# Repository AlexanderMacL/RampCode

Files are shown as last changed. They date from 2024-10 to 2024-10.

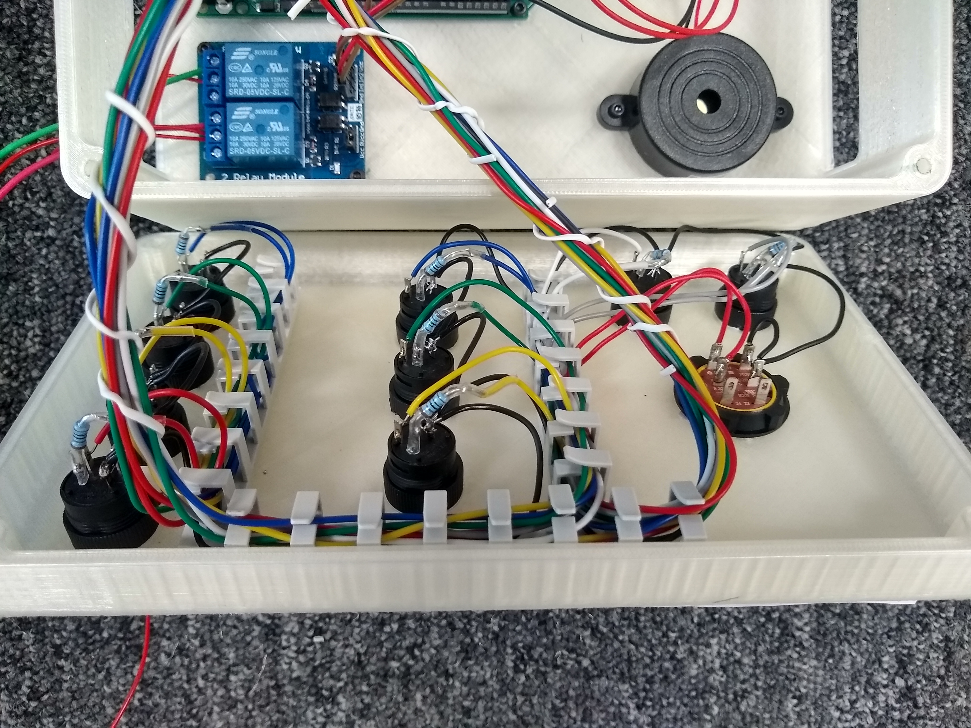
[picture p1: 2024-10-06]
Photos/IMG_20230616_105059777_HDR.jpg

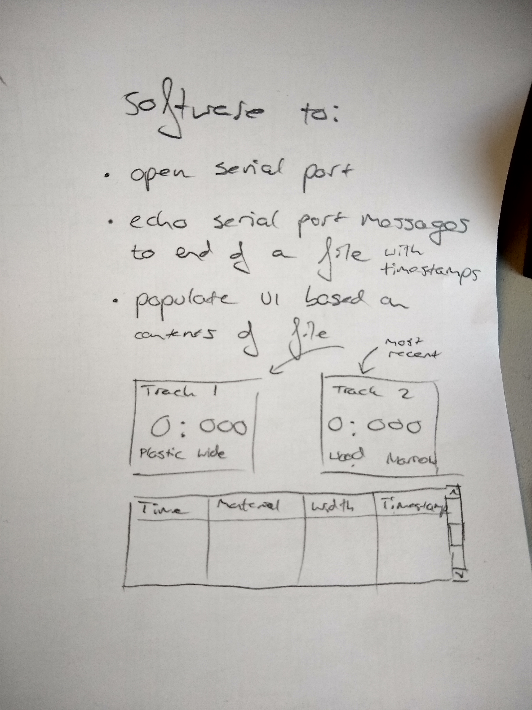
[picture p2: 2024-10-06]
Photos/IMG_20230616_143941583_HDR.jpg

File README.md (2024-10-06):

### Project Overview

- **`ControlPanel`**:  
  An Arduino app designed to run on an Arduino Mega (chosen for its ample IO capabilities to accommodate all the buttons).

- **`Leaderboard`**:  
  A WinForms Windows app designed to run on a Windows PC. It reads data sent by the Arduino through a serial port.

- **`MechDesign`**:  
  Contains various design files, including CAD files for the 3D-printed parts.

- **`Data`**:  
  Holds data obtained at the Great Exhibition Road Festival in 2023.

- **`Photos`**:  
  A collection of photos of the device.

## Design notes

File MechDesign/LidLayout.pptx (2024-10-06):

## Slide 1

Plastic

GO!

Twist to release

Narrow

Wood

Wide

Felt

Combo

1

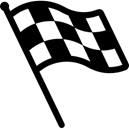
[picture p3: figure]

Track

2

Rubber

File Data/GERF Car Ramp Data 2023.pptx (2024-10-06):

## Total Runs by Material

When only one track was in use, the other, whatever its configuration, ‘did not finish’, so some of these may not have represented actual runs

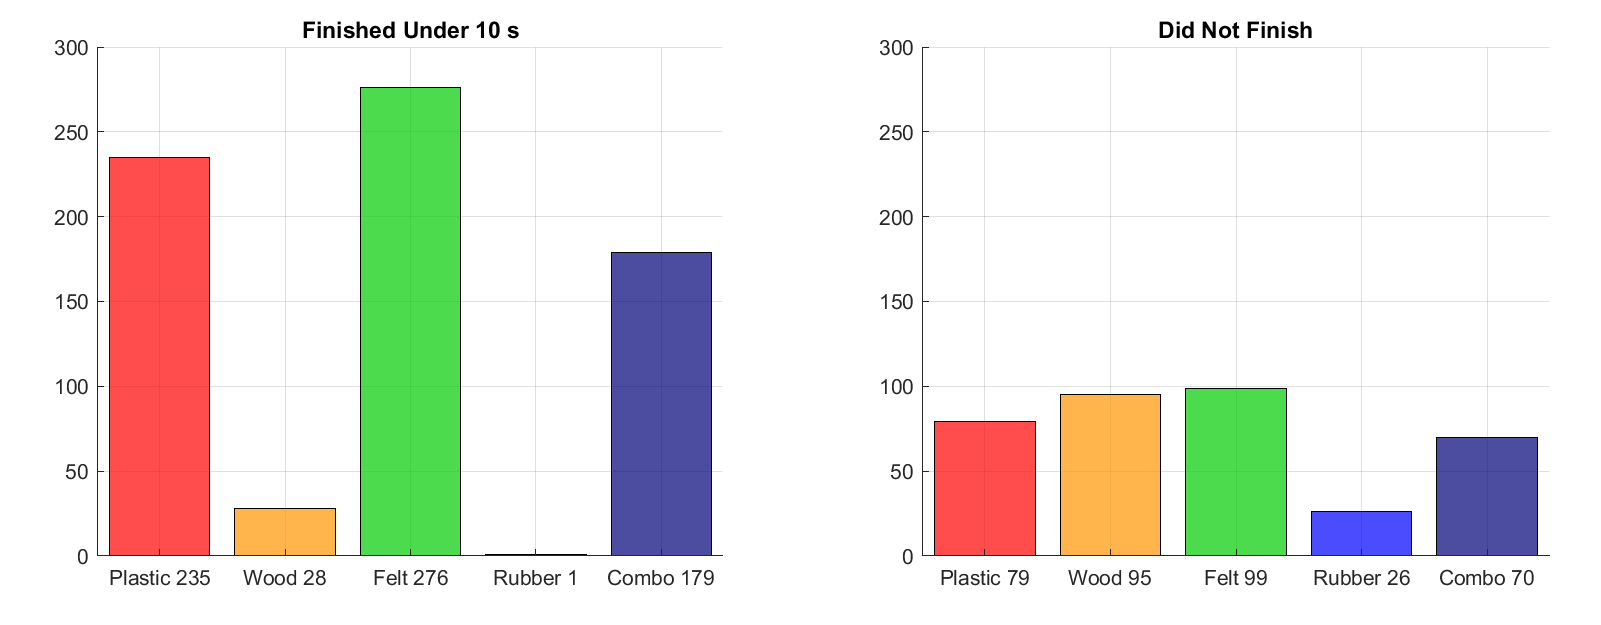
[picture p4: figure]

Over ¾ of wood did not finish the course. Rubber reliably did not finish.

## Frequency of Finish Time by Material

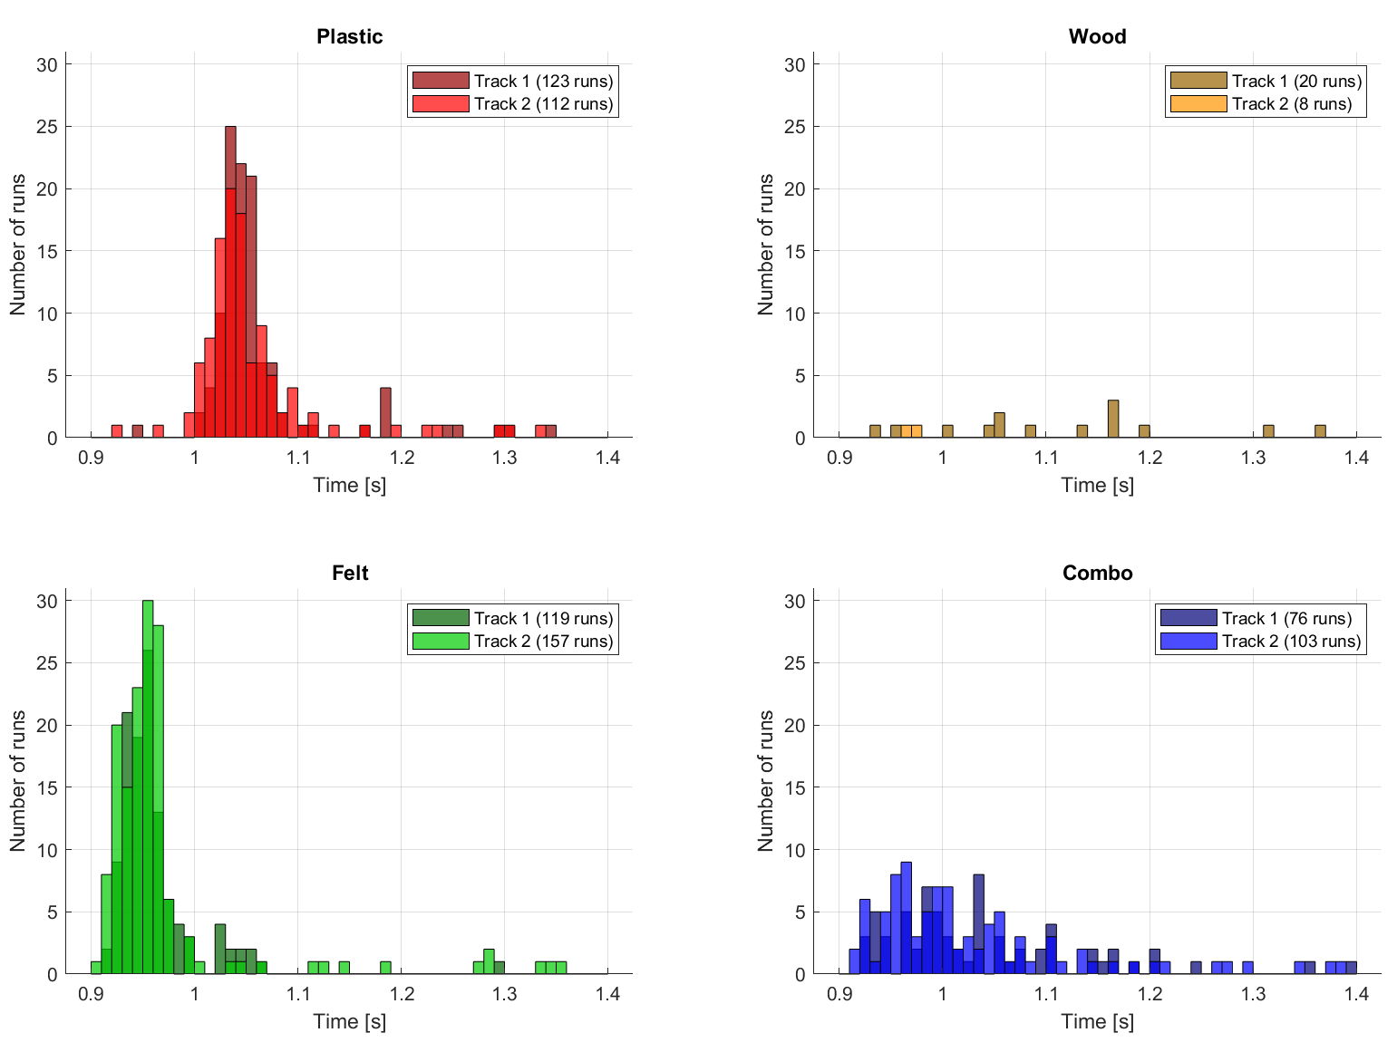
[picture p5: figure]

Felt is faster than plastic by ~0.08 s on average
(each bar represents 0.01 s)

Felt and plastic have similar standard deviations in finish time

Both tracks show the same trends and have the same mode finish time (bin size 10 ms)

## Frequency of Finish Time by Width

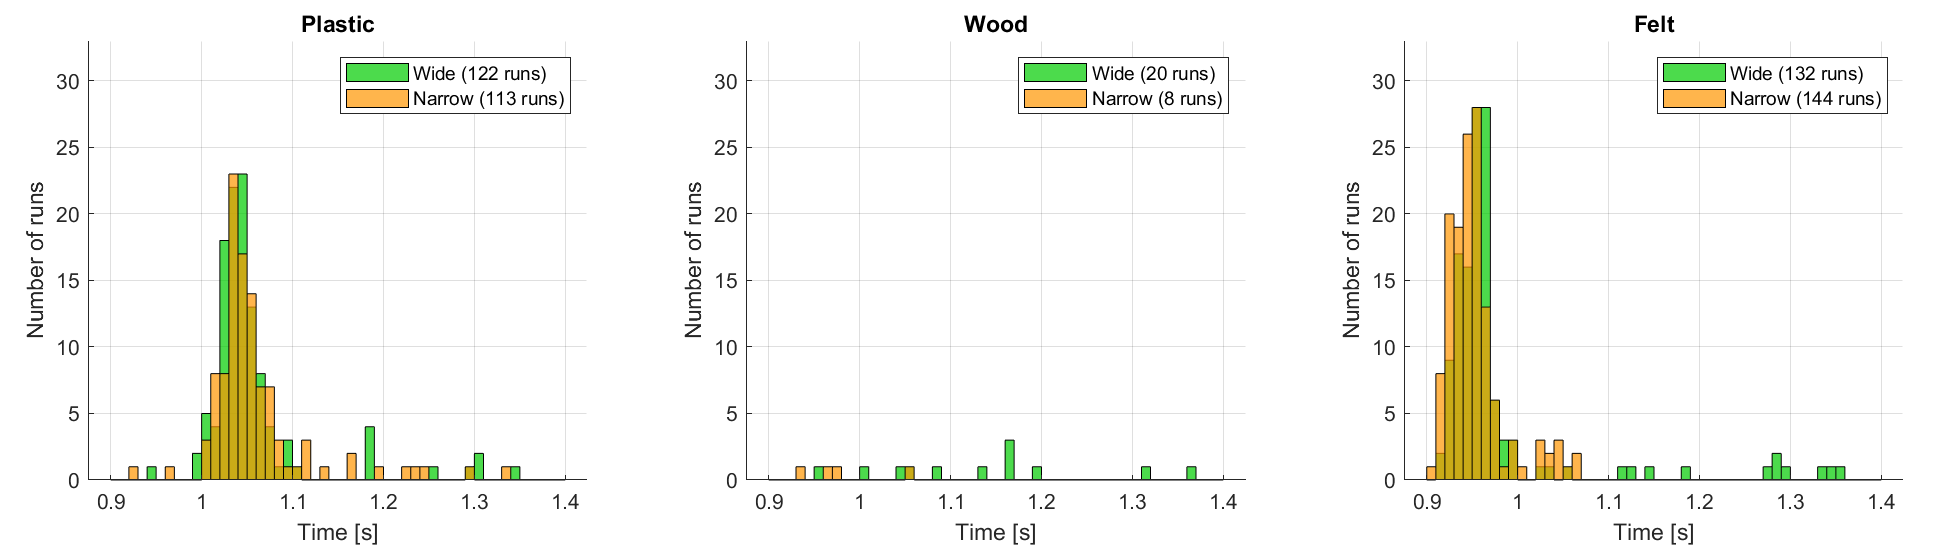
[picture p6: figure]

Mean finish time for narrow slightly faster than for wide for all materials

Results for wood are not statistically significant

Felt shows the most significant separation by width

## Activity Distribution by Time of Day

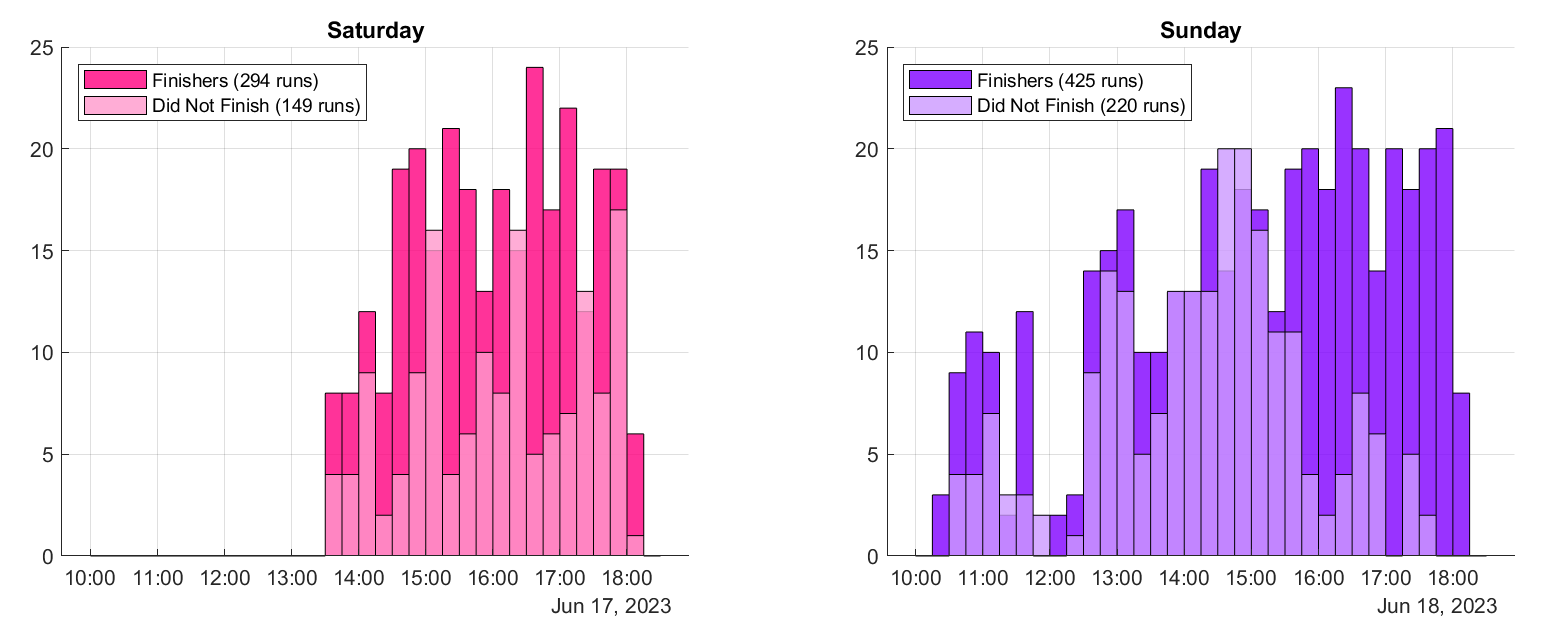
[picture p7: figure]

Regrettably, data from before lunchtime on Saturday was not recorded

The event officially opened 1100-1800

## Runs finishing in under 10 s

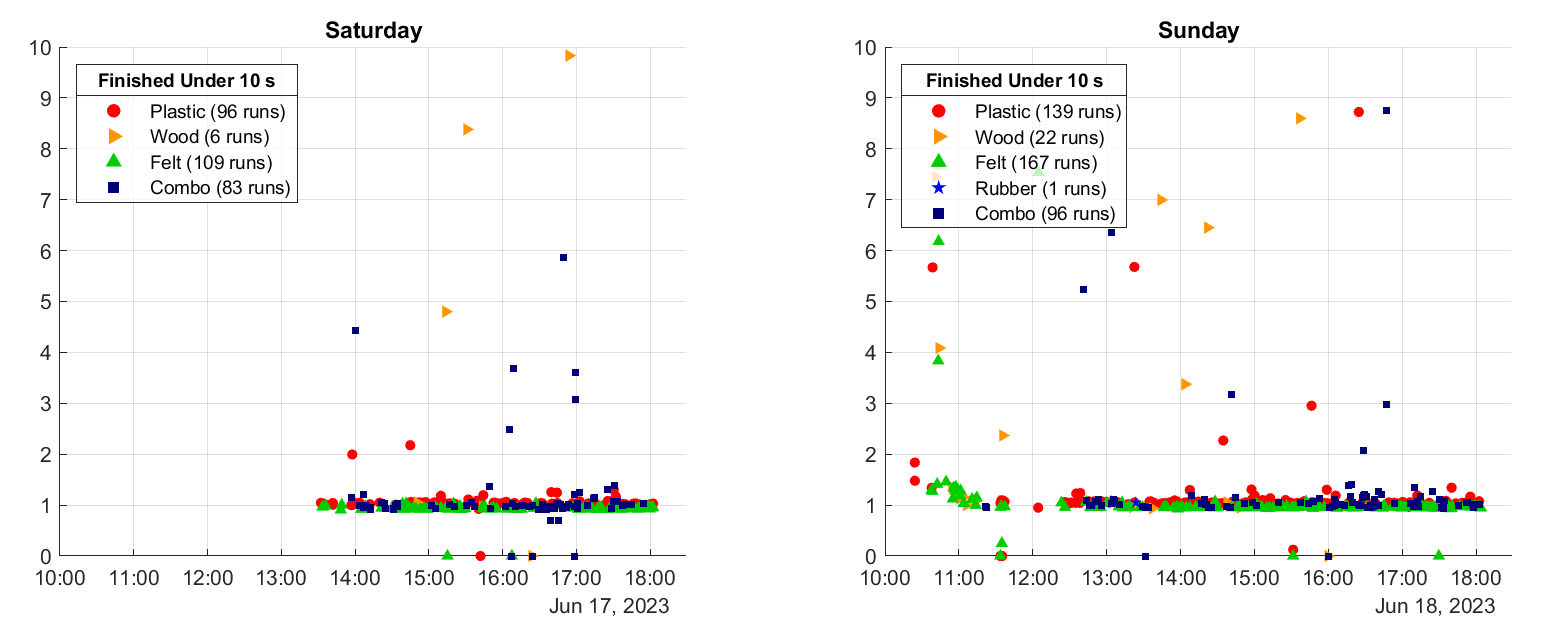
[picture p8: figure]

Runs taking more than 2 seconds occurred when cars did not finish but were not left for the full 10s, or due to other anomalies

## Runs finishing in under 2 s

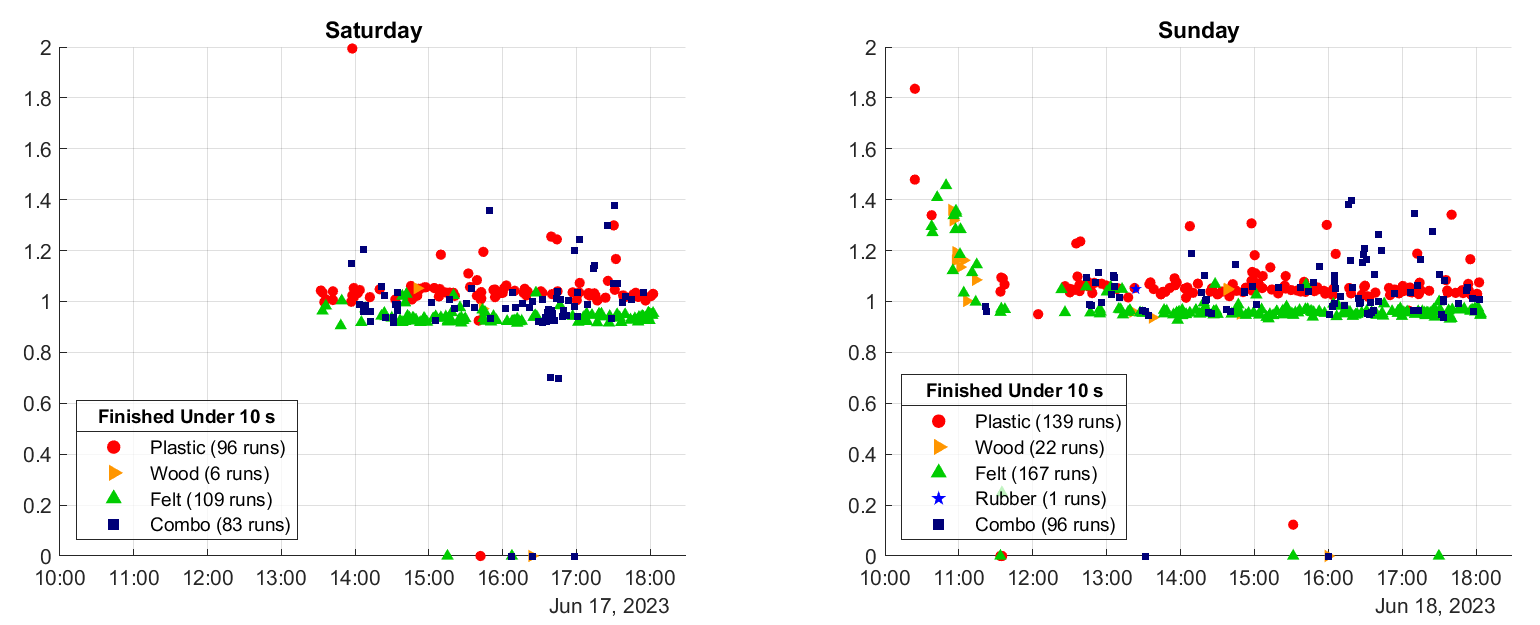
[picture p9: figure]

On Sunday the track had been cleaned overnight and for the first hour, finish times were appreciably longer until it became greasy again!

## Runs finishing in under 2 s by Track

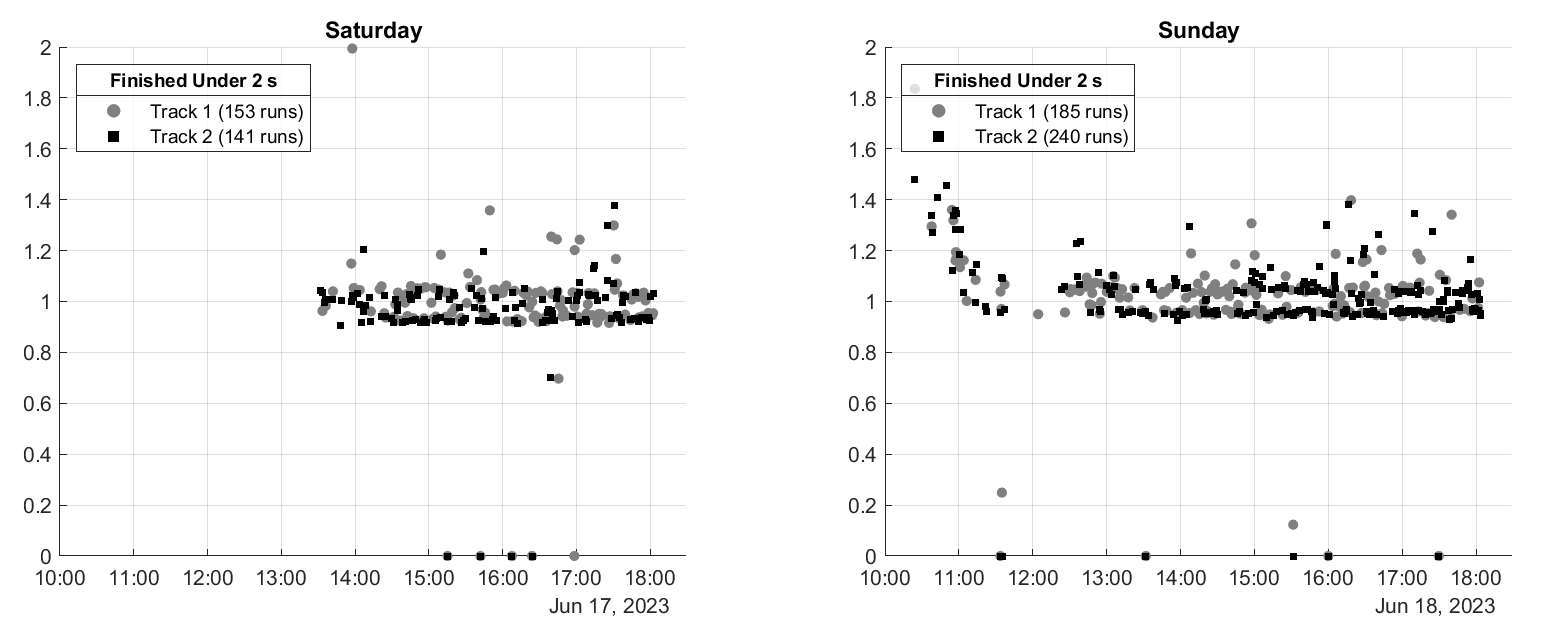
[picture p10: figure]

## Distribution of Finishers by Material

Visibility of leaderboard (showing felt to be most successful) and perhaps also intuition, created a consistent bias towards the faster materials

At approx. 1630 on both days, there was a spike in popularity of combos

This may coincide with the time that people’s uncles started joining in and trying to be clever

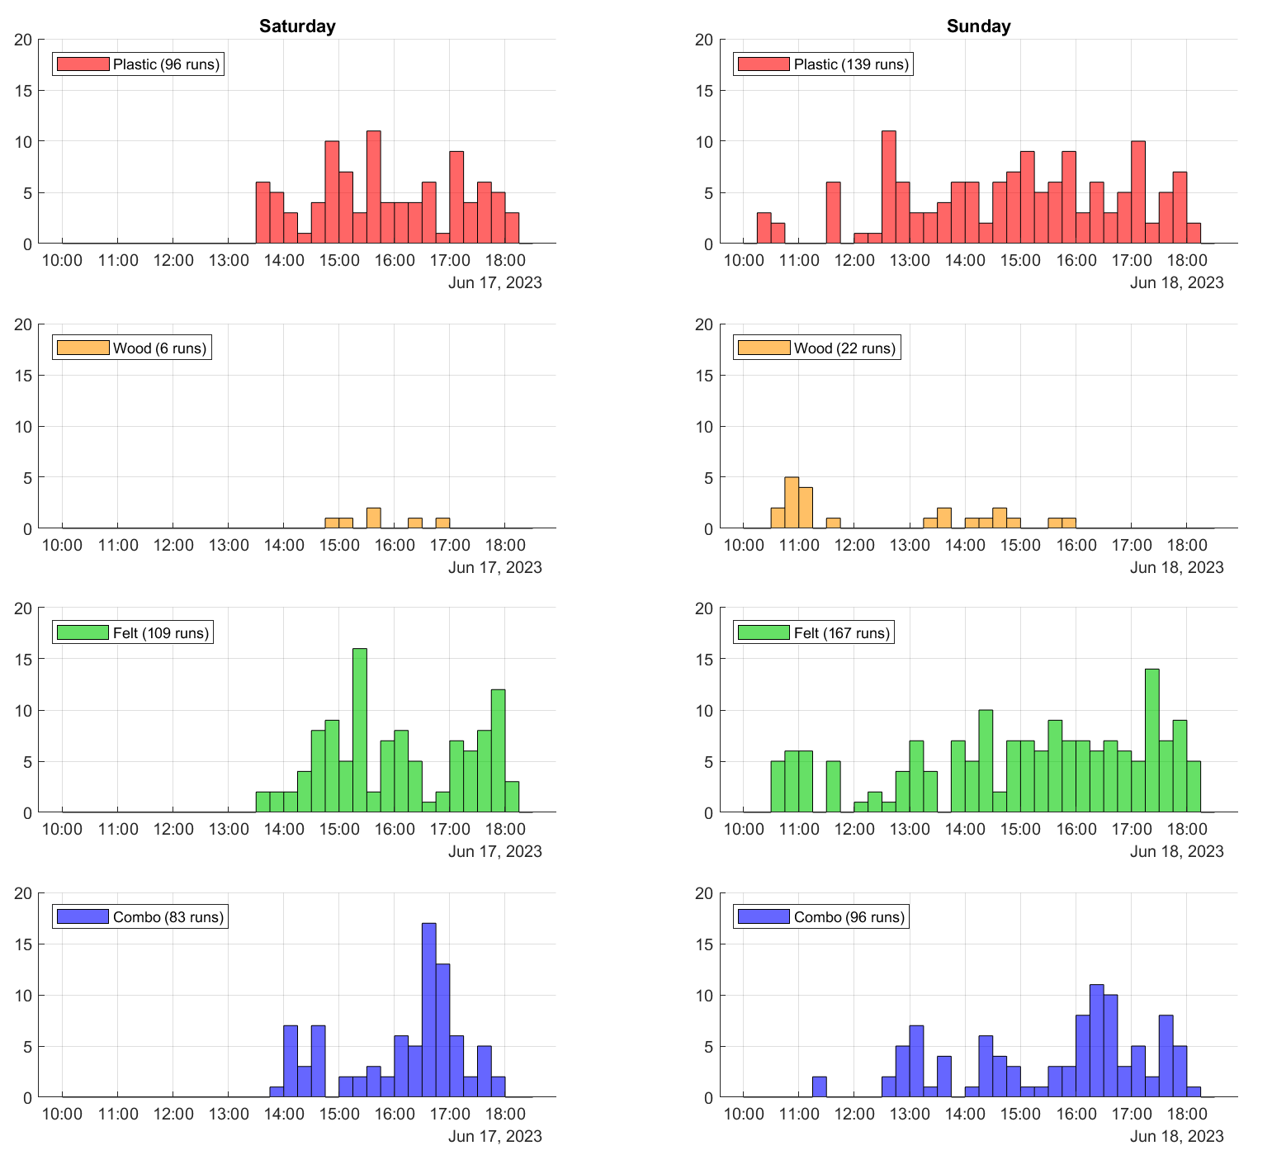
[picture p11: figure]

## Distribution of Did Not Finish by Material

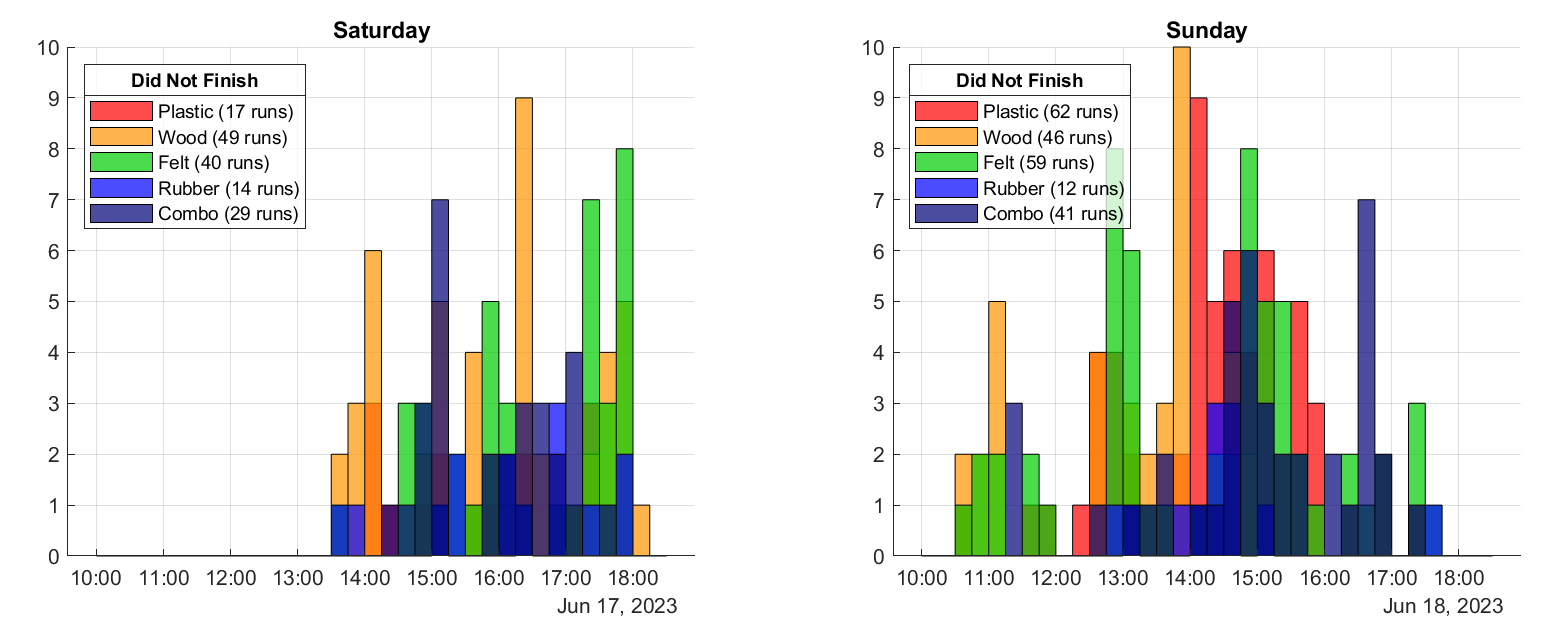
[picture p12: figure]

All 5 materials were, at different times, most frequent to not finish, for a variety of reasons including cars hitting the sides, solenoids failing to release, being assigned to a track not in use

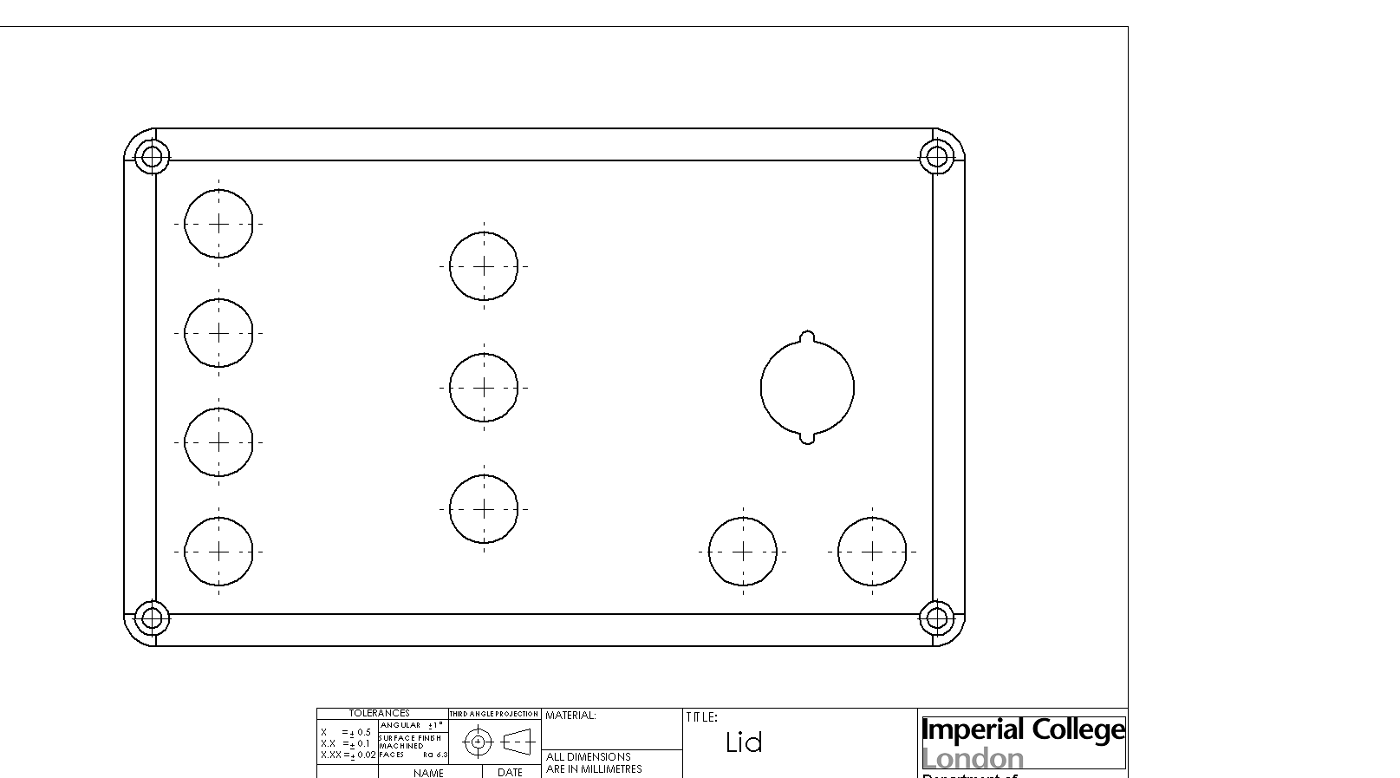
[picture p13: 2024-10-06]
MechDesign/Lid.PNG

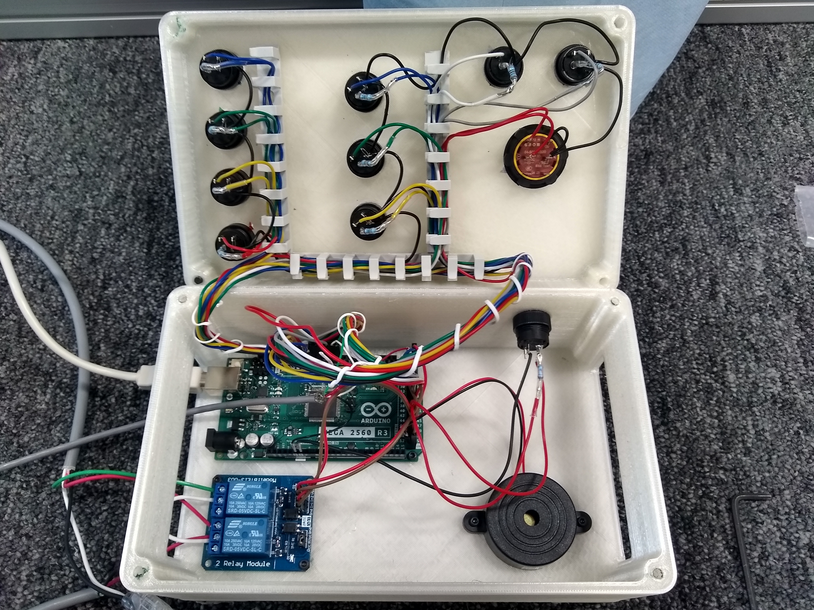
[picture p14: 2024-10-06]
Photos/IMG_20230616_121205236_HDR.jpg

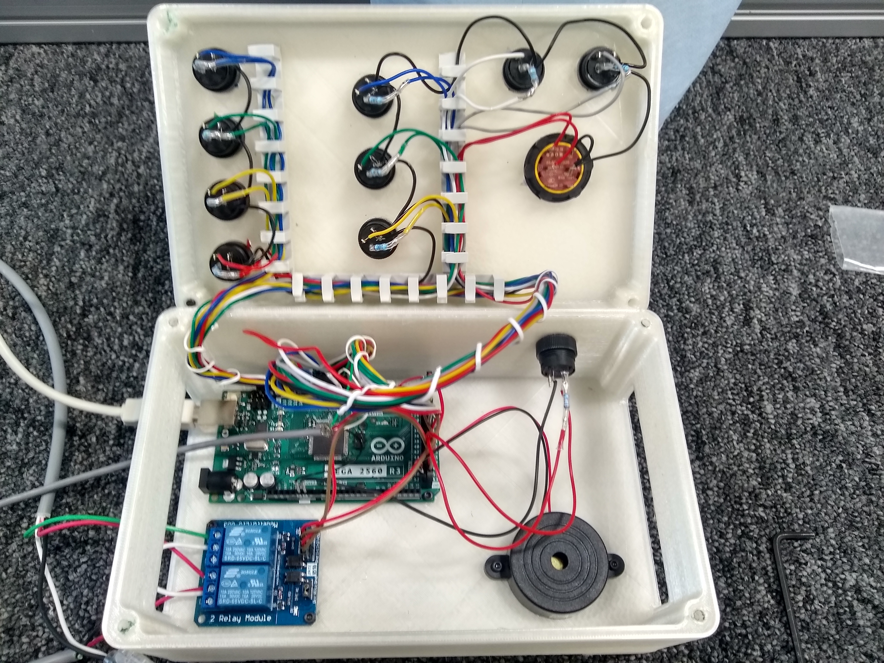
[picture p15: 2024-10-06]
Photos/IMG_20230616_121215515_HDR.jpg

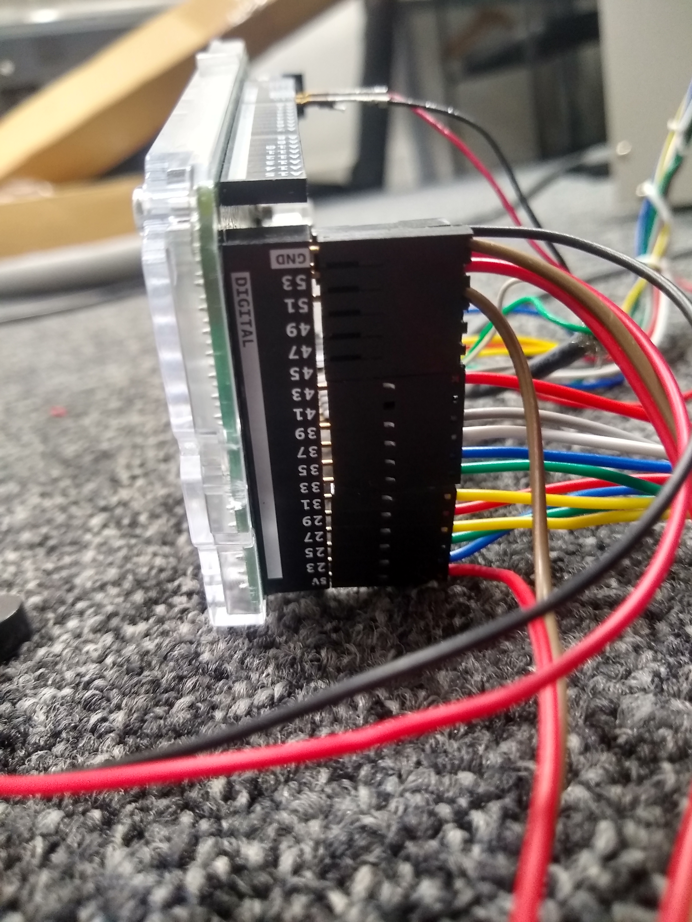
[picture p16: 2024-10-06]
Photos/IMG_20230615_212253774_HDR.jpg

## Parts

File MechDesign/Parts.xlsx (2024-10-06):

Name | Quantity | RS number | Cost | Link
Relay bank | 2 | 265-1120 | £11.60 | https://uk.rs-online.com/web/p/power-motor-robotics-development-tools/2651120
Switch | 1 | 477-4907 | £30.50 | https://uk.rs-online.com/web/p/emergency-stop-push-buttons/4774907
Buzzer | 1 | 617-3097 | £3.92 | https://uk.rs-online.com/web/p/piezo-buzzers/6173097
Optosensor | 2 | 627-8388 | £13.60 | https://uk.rs-online.com/web/p/photoelectric-sensors/6278388
Arduino Mega | 1 | 715-4084 | £35.95 | https://uk.rs-online.com/web/p/arduino/7154084
USB Cable | 1 | 182-8549 | £2.95 | https://uk.rs-online.com/web/p/usb-cables/1828549

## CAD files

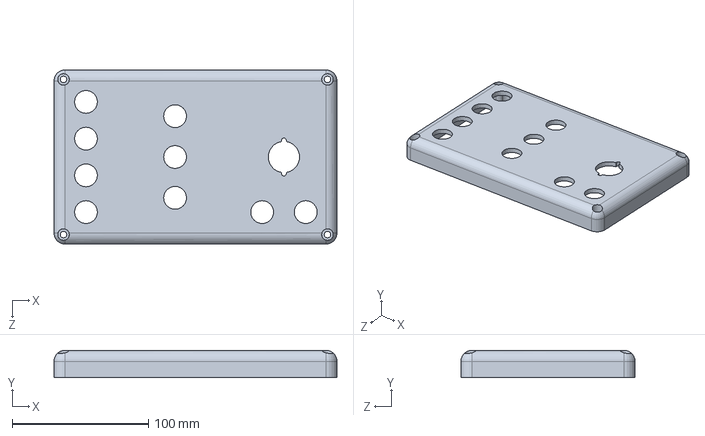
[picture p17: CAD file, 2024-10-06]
MechDesign/Lid.SLDPRT
208.0 x 20.0 x 128.0 mm

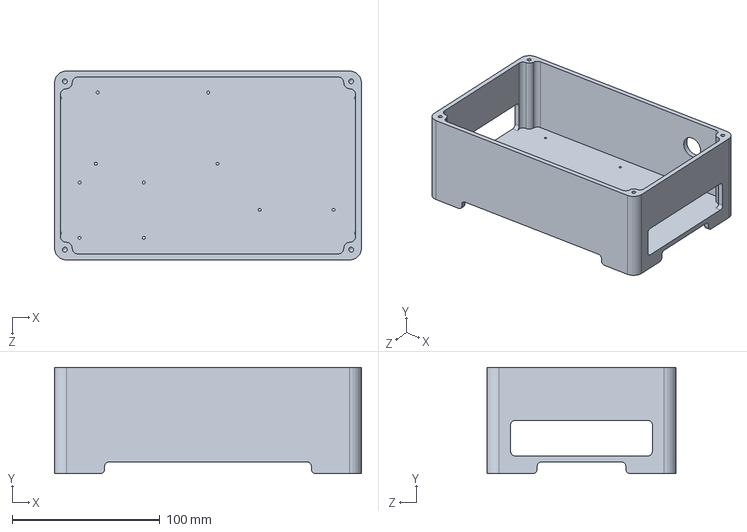
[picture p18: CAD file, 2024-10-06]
MechDesign/Box.SLDPRT
208.0 x 72.0 x 128.0 mm

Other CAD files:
MechDesign/Box.STL
MechDesign/Lid.STL

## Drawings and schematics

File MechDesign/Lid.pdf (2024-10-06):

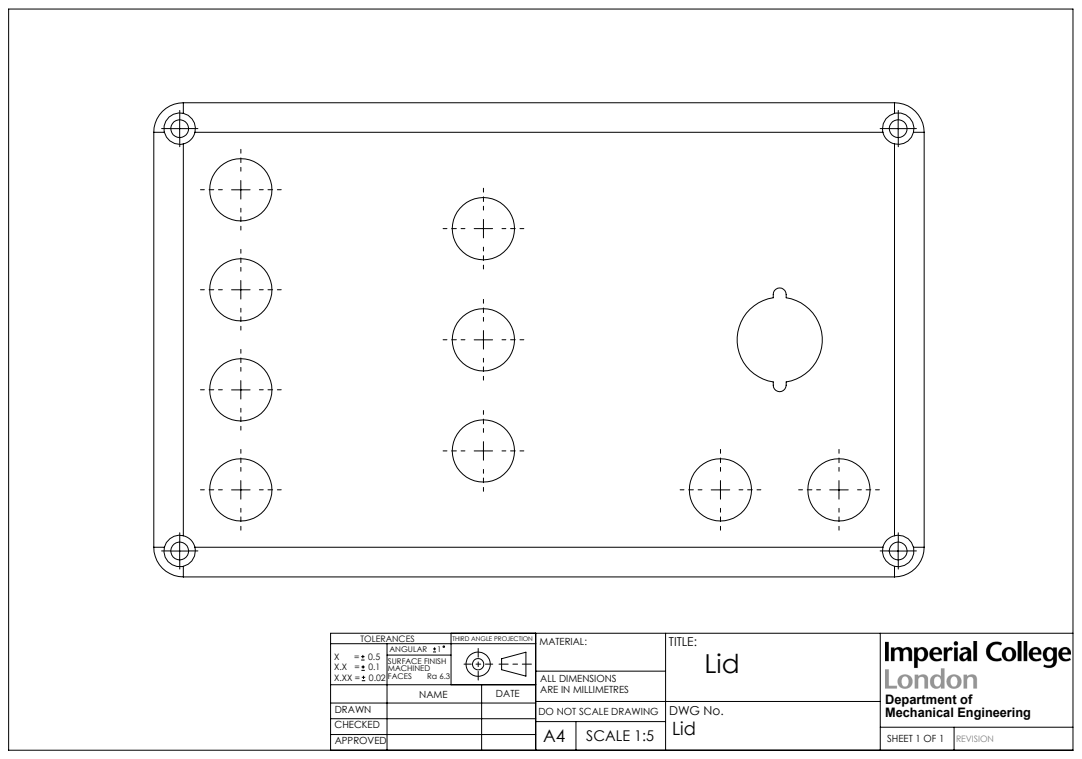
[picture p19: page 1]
SURFACE FINISH; FACES; DWG No.; A4 SCALE 1:5; SHEET 1 OF 1; Department of Mechanical Engineering

THIRD ANGLE PROJECTION

ALL DIMENSIONS
ARE IN MILLIMETRES
DO NOT SCALE DRAWING

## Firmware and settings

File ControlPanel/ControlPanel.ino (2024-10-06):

#define OPTO_1_PIN 3
#define OPTO_2_PIN 2
#define RELAY_1_PIN 51
#define RELAY_2_PIN 53
#define GO_BUTTON_PIN 43
#define GO_LED_PIN 8
#define A1_LED_PIN 10
#define A2_LED_PIN 11
#define A3_LED_PIN 12
#define A4_LED_PIN 13
#define B1_LED_PIN 9
#define B2_LED_PIN 7
#define B3_LED_PIN 6
#define B4_LED_PIN 45
#define TRACK_1_LED_PIN 5
#define TRACK_2_LED_PIN 4
#define A1_BUTTON_PIN 29
#define B1_BUTTON_PIN 31
#define B2_BUTTON_PIN 33
#define B3_BUTTON_PIN 35
#define A2_BUTTON_PIN 27
#define A3_BUTTON_PIN 25
#define A4_BUTTON_PIN 23
#define B4_BUTTON_PIN 47


#define TRACK_1_BUTTON_PIN 37
#define TRACK_2_BUTTON_PIN 39
#define BUZZER_PIN 52

#define TIMEOUT_SECONDS 10


// TODO
// Go button to relays
// Go button LED
// Radio Button code
// Combo Button code
// PWM LEDS

volatile bool timingflag = false;
volatile bool recordtimeflag = false;
bool newtimeflag = false;
unsigned long starttime, endtime, pulsewidth;
bool raceinprogress = false;
bool golatch = false;
unsigned long racestart = 0, raceend1 = 0, raceend2 = 0;
bool relay_1_on = false, relay_2_on = false;

class LatchingButton {
  public:
    LatchingButton(int p, int lp) {
      pin = p;
      ledPin = lp;
      state = false;
      buttonstate = false;
      buttonpressed = false;
    }
    int pin;
    int ledPin;
    bool state;
    bool buttonstate;
    bool buttonpressed;
    void updateButton() {
      buttonstate = digitalRead(pin) == LOW;
      if (!buttonpressed && buttonstate) {
        buttonpressed = true;
        state = !state;
      } else if (buttonpressed && !buttonstate) {
        buttonpressed = false;
      }
      digitalWrite(ledPin, state ? HIGH : LOW);
    }
};

LatchingButton BuzzerButton(B4_BUTTON_PIN, B4_LED_PIN);
LatchingButton Track1Button(TRACK_1_BUTTON_PIN, TRACK_1_LED_PIN);
LatchingButton Track2Button(TRACK_2_BUTTON_PIN, TRACK_2_LED_PIN);
LatchingButton ComboButton(B3_BUTTON_PIN, B3_LED_PIN);

enum Material {
  Plastic = 0,
  Wood = 1,
  Felt = 2,
  Rubber = 3
};
const int materialLEDs[4] = {A1_LED_PIN, A2_LED_PIN, A3_LED_PIN, A4_LED_PIN};
const int materialButtons[4] = {A1_BUTTON_PIN, A2_BUTTON_PIN, A3_BUTTON_PIN, A4_BUTTON_PIN};

enum Width {
  Narrow = 0,
  Wide = 1
};
const int widthLEDs[4] = {B1_LED_PIN, B2_LED_PIN};
const int widthButtons[4] = {B1_BUTTON_PIN, B2_BUTTON_PIN};

class TrackState {
  public:
    TrackState(int tracknum) {
      tracknumber = tracknum;
      // defaults
      material = Plastic;
      width = Wide;
      combo = true;
      enabled = false;
    }
    Material material;
    Width width;
    bool combo;
    bool enabled;
    int tracknumber;
    void ShowState();
    void UpdateState();
    void CopyFromState(TrackState& t);
    void SendState();
};

const int trackLEDs[4] = {TRACK_1_LED_PIN, TRACK_2_LED_PIN};
const int trackButtons[4] = {TRACK_1_BUTTON_PIN, TRACK_2_BUTTON_PIN};

void TrackState::ShowState() {
  for (int i = 0; i < 4; i++) {
    // turn all the LEDs off except the selected one
    if (material == i && !combo) digitalWrite(materialLEDs[i], HIGH);
    else digitalWrite(materialLEDs[i], LOW);
    if (i < 2) {
      if (width == i && !combo) digitalWrite(widthLEDs[i], HIGH);
      else digitalWrite(widthLEDs[i], LOW);
    }
  }
  ComboButton.state = combo;
  ComboButton.updateButton();
}

void TrackState::UpdateState() {
  if (enabled) {
    for (int i = 0; i < 4; i++) {
      if (digitalRead(materialButtons[i]) == LOW) { // buttons are active low
        material = (Material)i;
        ComboButton.state = false;
      }
      if (i < 2 && digitalRead(widthButtons[i]) == LOW) {
        width = (Width)i;
        ComboButton.state = false;
      }
    }
    combo = ComboButton.state;
    ShowState();
  }
}

void TrackState::CopyFromState(TrackState& t) {
  material = t.material;
  width = t.width;
  combo = t.combo;
}

void TrackState::SendState() {
  Serial.print("T"); Serial.print(tracknumber);
  Serial.print(",M"); Serial.print((int)material);
  Serial.print(",W"); Serial.print((int)width);
  Serial.print(",C"); Serial.print(combo ? 1 : 0);
}

void ISR_OPTO_1() {
  if (digitalRead(OPTO_1_PIN) == HIGH) {
    if (!timingflag && !recordtimeflag) {
      recordtimeflag = true;
    }
  } else {
    if (timingflag && !recordtimeflag) {
      recordtimeflag = true;
    }
  }
}

TrackState track1state(1);
TrackState track2state(2);

void setup() {
  // put your setup code here, to run once:
  pinMode(OPTO_1_PIN, INPUT);
  pinMode(RELAY_1_PIN, OUTPUT);
  pinMode(RELAY_2_PIN, OUTPUT);
  pinMode(GO_LED_PIN, OUTPUT);
  pinMode(BUZZER_PIN, OUTPUT);
  pinMode(TRACK_1_LED_PIN, OUTPUT);
  pinMode(TRACK_2_LED_PIN, OUTPUT);
  pinMode(A1_LED_PIN, OUTPUT);
  pinMode(A2_LED_PIN, OUTPUT);
  pinMode(A3_LED_PIN, OUTPUT);
  pinMode(A4_LED_PIN, OUTPUT);
  pinMode(B1_LED_PIN, OUTPUT);
  pinMode(B2_LED_PIN, OUTPUT);
  pinMode(B3_LED_PIN, OUTPUT);
  pinMode(B4_LED_PIN, OUTPUT);
  pinMode(GO_BUTTON_PIN, INPUT_PULLUP);
  pinMode(A1_BUTTON_PIN, INPUT_PULLUP);
  pinMode(A2_BUTTON_PIN, INPUT_PULLUP);
  pinMode(A3_BUTTON_PIN, INPUT_PULLUP);
  pinMode(A4_BUTTON_PIN, INPUT_PULLUP);
  pinMode(B1_BUTTON_PIN, INPUT_PULLUP);
  pinMode(B2_BUTTON_PIN, INPUT_PULLUP);
  pinMode(B3_BUTTON_PIN, INPUT_PULLUP);
  pinMode(B4_BUTTON_PIN, INPUT_PULLUP);
  pinMode(TRACK_1_BUTTON_PIN, INPUT_PULLUP);
  pinMode(TRACK_2_BUTTON_PIN, INPUT_PULLUP);
  //  attachInterrupt(digitalPinToInterrupt(OPTO_1_PIN),ISR_OPTO_1,CHANGE);
  Serial.begin(115200);
//  while (!Serial);
  ComboButton.state = true;
  Track2Button.state = false;
  BuzzerButton.state = true;
  track2state.enabled = true;
}

unsigned long timestamp = 0;
unsigned long lastupdate = 0;
int refreshinterval = 500;
bool redLEDon = false;
bool track1enabled = true;
bool track2enabled = true;

void LEDPWM();
int pwm = 0;
int pwmup = 0;
int pwmdown = 0;

void loop() {
  // put your main code here, to run repeatedly:
  timestamp = millis();
  //  if (recordtimeflag) {
  //    if (!timingflag) {
  //      starttime = timestamp;
  //      timingflag = true;
  //    } else {
  //      endtime = timestamp;
  //      pulsewidth = endtime - starttime;
  //      timingflag = false;
  //      newtimeflag = true;
  //    }
  //    recordtimeflag = false;
  //  }

  // couple GO button to relay pins if tracks are enabled
  if (digitalRead(GO_BUTTON_PIN) == HIGH) { // because although switches are active-low, this is wired to the NC terminals on the GO button
    if (!raceinprogress && !golatch) {
      relay_1_on = true;
      relay_2_on = true;
      analogWrite(GO_LED_PIN, 255);
      racestart = millis();
      raceend1 = 0;
      raceend2 = 0;
      raceinprogress = true;
      golatch = true;
    }
  } else {
//    digitalWrite(RELAY_1_PIN, HIGH);
//    digitalWrite(RELAY_2_PIN, HIGH);
    LEDPWM();
    raceinprogress = false;
    golatch = false;
    relay_1_on = false;
    relay_2_on = false;
  }
  // couple optosensors to Buzzer
  digitalWrite(BUZZER_PIN, (BuzzerButton.state && (digitalRead(OPTO_1_PIN) == HIGH || digitalRead(OPTO_2_PIN) == HIGH)) ? HIGH : LOW);
  // check if race should end
  bool timedout = (timestamp - racestart) > 1000UL * TIMEOUT_SECONDS;
  if (raceinprogress) {
    if ((digitalRead(OPTO_1_PIN) == HIGH && raceend1 == 0) || (timedout && raceend1 == 0)) {
      //if (!timedout) {
        raceend1 = millis();
        track1state.SendState();
        Serial.print(",");
        Serial.println(raceend1 - racestart);
      //}
      relay_1_on = false;
      if (((raceend1 > 0) && (raceend2 > 0)) || timedout) {
        raceinprogress = false;
        analogWrite(GO_LED_PIN, 0);
      }
    }
    if ((digitalRead(OPTO_2_PIN) == HIGH && raceend2 == 0) || (timedout && raceend2 == 0)) {
      //if (!timedout) {
        raceend2 = millis();
        track2state.SendState();
        Serial.print(",");
        Serial.println(raceend2 - racestart);
      //}
      relay_2_on = false;
      if (((raceend1 > 0) && (raceend2 > 0)) || timedout) {
        raceinprogress = false;
        analogWrite(GO_LED_PIN, 0);
      }
    }
  }
  // check latching buttons
  Track1Button.updateButton();
  Track2Button.updateButton();
  if ((!Track1Button.state && !Track2Button.state) || (Track1Button.state && Track2Button.state)) { // if neither enabled, enable the one not just pressed
    Track1Button.state = track2state.enabled;
    Track2Button.state = track1state.enabled;
    track1state.enabled = Track1Button.state;
    track2state.enabled = Track2Button.state;
    Track1Button.updateButton();
    Track2Button.updateButton();
  }
  // if both enabled, copy the state of the one just enabled to the other one
  //  if (Track1Button.state && Track2Button.state && (!track1state.enabled || !track2state.enabled)) {
  //    if (!track2state.enabled) {
  //      track1state.CopyFromState(track2state);
  //    }
  //    if (!track1state.enabled) {
  //      track2state.CopyFromState(track1state);
  //    }
  //  }
  if (Track1Button.state) { // if Track 1 is enabled, show the state
    track1state.enabled = Track1Button.state;
    if (track1state.enabled) track1state.ShowState();
  }
  if (Track2Button.state) { // if Track 2 is enabled, show the state
    track2state.enabled = Track2Button.state;
    if (track2state.enabled) track2state.ShowState();
  }

  track1state.UpdateState();
  track2state.UpdateState();

  BuzzerButton.updateButton();

  // update relays
  digitalWrite(RELAY_1_PIN, (relay_1_on) ? LOW : HIGH);
  digitalWrite(RELAY_2_PIN, (relay_2_on) ? LOW : HIGH);

  //  if (newtimeflag) {
  //    noInterrupts();
  //    Serial.print("Pulse detected at ");
  //    Serial.print((float)timestamp/1000.0);
  //    Serial.print(" s, pulse width ");
  //    Serial.print((float)pulsewidth/1000.0);
  //    Serial.println(" ms");
  //    newtimeflag = false;
  //    interrupts();
  //  }
  //  if (timestamp-lastupdate > refreshinterval) {
  //    lastupdate = timestamp;
  //    if (!redLEDon) { // toggle red LED
  //      digitalWrite(RED_LED_PIN,HIGH);
  //      redLEDon = true;
  //    } else {
  //      digitalWrite(RED_LED_PIN,LOW);
  //      redLEDon = false;
  //    }
  //  }
}

void LEDPWM() {
  if (timestamp - lastupdate > 25) {
    lastupdate = timestamp;
    if (pwmup < 256) pwmup += 8;
    else if (pwmdown < 256) pwmdown += 8;
    else {
      pwmup = 0;
      pwmdown = 0;
    }
    pwm = pwmup - pwmdown;
    if (pwm > 255) pwm = 255;
    analogWrite(GO_LED_PIN, pwm);
  }
}
